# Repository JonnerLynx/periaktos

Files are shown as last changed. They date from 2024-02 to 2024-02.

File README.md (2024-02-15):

# periaktos
A periaktos design for theater sets.

Each side of the periaktos is a full 4'x8' sheet of 5mm plywood (AKA luan). Each periaktos sits on top of a 2' pedestal. The pedestal has a 1/2" iron pipe extending up through the center of the periaktos to keep it centered. To prevent tipping, each periaktos has a low center of gravity and the pedestal is designed accommodate extra ballast weight. The primary structural materials are 2"x4" lumber and 1/2" OSB sheathing.

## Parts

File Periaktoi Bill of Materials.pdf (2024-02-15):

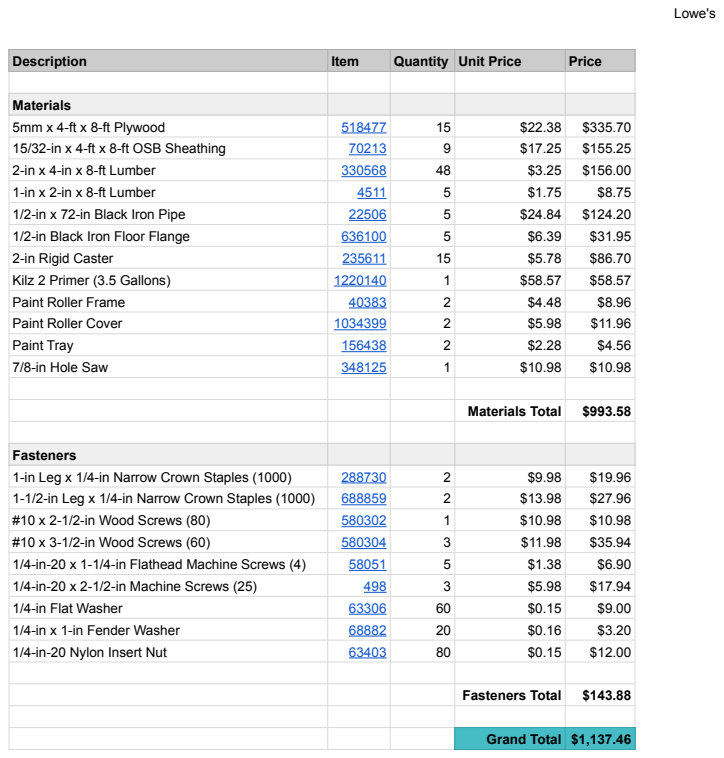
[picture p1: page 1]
Lowe's; Description; Item; Quantity Unit Price; Price; Materials; 5mm x 4-ft x 8-ft Plywood; 15/32-in x 4-ft x 8-ft OSB Sheathing; 2-in x 4-in x 8-ft Lumber; 1-in x 2-in x 8-ft Lumber; 1/2-in x 72-in Black Iron Pipe; 1/2-in Black Iron Floor Flange; 2-in Rigid Caster; Kilz 2 Primer (3.5 Gallons); Paint Roller Frame; Paint Roller Cover; Paint Tray; 7/8-in Hole Saw; Materials Total; Fasteners; 1-in Leg x 1/4-in Narrow Crown Staples (1000); 1-1/2-in Leg x 1/4-in Narrow Crown Staples (1000)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

McMaster Carr

Description | Item | Quantity | Unit Price | Price
Swivel Leveling Mount, 2-1/2" Long 1/4"-20 Threaded Stud | 6111K148 (https://www.mcmaster.com/6111K148/) | 15 | $7.22 | $108.30
Steel Tee Nut Inserts, 1/4"-20 (25) | 90975A063 (https://www.mcmaster.com/90975A063/) | 1 | $10.80 | $10.80
Total | $119.10

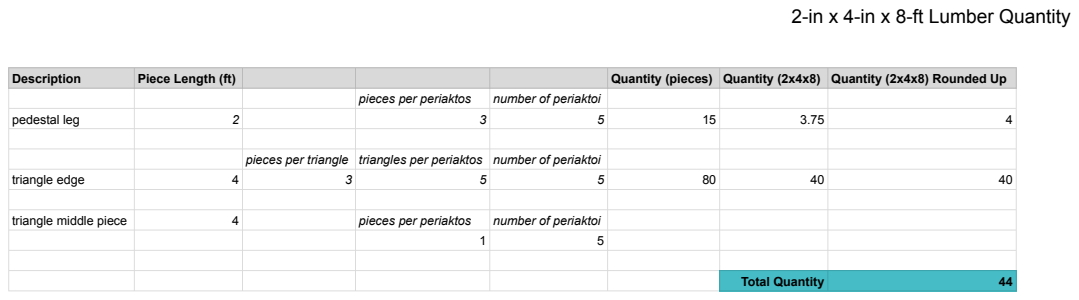
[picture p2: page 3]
Description; Piece Length (ft); Quantity (pieces) Quantity (2x4x8) Quantity (2x4x8) Rounded Up; pieces per periaktos; number of periaktoi; pedestal leg; triangle edge; triangle middle piece; Total Quantity

2-in x 4-in x 8-ft Lumber Quantity

pieces per triangle triangles per periaktos number of periaktoi

Primer Quantity

Width (ft) | Height (ft) | Count | Total Area (sq ft) | Coverage (sq ft per gallon) | Number of Coats
4 | 8 | 19 | 608 | 350 | 2
Quantity (gallons) | 3.47

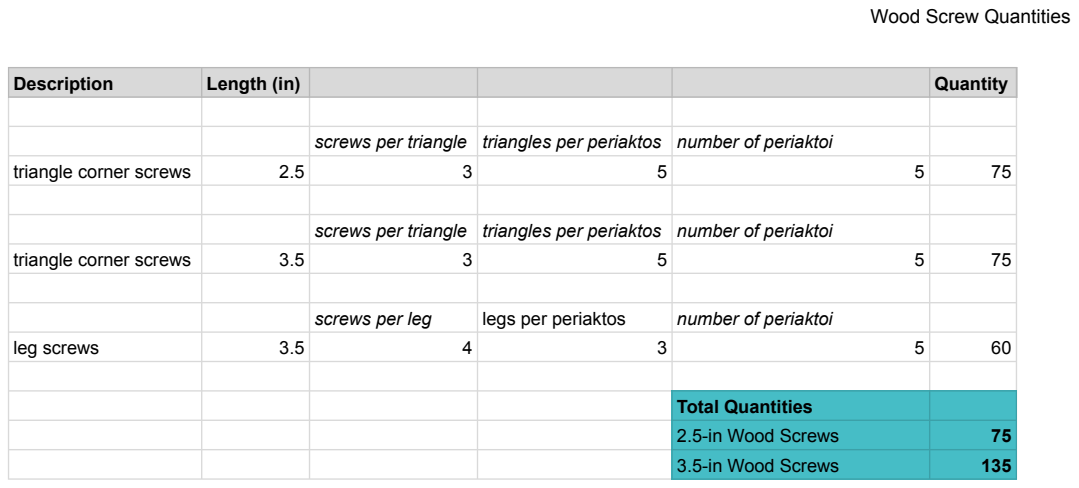
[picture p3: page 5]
Description; Length (in); Quantity; triangle corner screws; screws per leg; legs per periaktos; number of periaktoi; leg screws; Total Quantities; 2.5-in Wood Screws; 3.5-in Wood Screws

Wood Screw Quantities

screws per triangle triangles per periaktos number of periaktoi

Machine Screw Length

Item | Length (in) | Length (in) Rounded Up

Floor Flange Assembly
Floor Flange | 0.210
OSB Sheathing | 0.469
Fender Washer | 0.048
Nylon Insert Nut | 0.308
Total Length | 1.03 | 1-1/4"

Caster Assembly

Caster | 0.095
OSB Sheathing | 0.469
2-in x 4-in Lumber | 1.500
Flat Washer | 0.055
Nylon Insert Nut | 0.308
Total Length | 2.43 | 2-1/2"

Weight

Item | Weight (lbs)

Periaktos
Bottom Triangle | 26.2
Middle Triangle | 24.9
Top Triangle | 12.9
OSB Supports | 35.4
Plywood Panels | 48.9
Total | 148.3
Pedestal | 63.5
Grand Total | 211.8

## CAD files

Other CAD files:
Periaktos.f3d
